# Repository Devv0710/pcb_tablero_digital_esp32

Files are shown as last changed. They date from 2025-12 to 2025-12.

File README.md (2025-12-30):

Este documento detalla las especificaciones técnicas y decisiones de diseño de hardware para la PCB de control de un tablero marcador digital. El sistema está basado en el microcontrolador **ESP8266 (Wemos D1 Mini)** y está diseñado para gestionar tiras LED direccionables de alta potencia y periféricos inductivos.

> **[IMAGEN 1: VISTA GENERAL DE LA PCB]**
>pcb

## 1. Arquitectura de Distribución de Potencia

El diseño gestiona dos rieles de alimentación independientes para evitar que el ruido de los actuadores y la carga de los LEDs interfieran con la estabilidad del microcontrolador.

> **[IMAGEN 2: DIAGRAMA DE BLOQUES DE POTENCIA U ORDENACIÓN FÍSICA]**
>
>

### Rail de Potencia Principal (5V)
* **Carga de LEDs:** El sistema controla 13 dígitos. El consumo máximo teórico es de **7.6A** (blanco al 100% de brillo), con un consumo típico de **400mA** por dígito en operación estándar.
* **Plano de Cobre:** Para soportar esta corriente sin caídas de tensión significativas (IR Drop), se utilizó un **plano de potencia de cobre** en la capa superior (Top Layer).
* **Protección:** Un fusible de acción rápida de **10A** (**F1**) protege la integridad de las pistas y componentes ante cortocircuitos en las tiras externas.

### Rail de Periféricos (12V)
* **Función:** Alimentación exclusiva para una bocina externa de alta potencia.
* **Consumo:** Optimizado para cargas menores a **1A**.
* **Control Electrónico:** Implementado mediante un MOSFET N-Channel **AO3400A**. 
* **Protección Inductiva:** Se incluyó un diodo de libre circulación (**1N4007**) en paralelo con la carga para suprimir los picos de fuerza contraelectromotriz al conmutar la bocina.  

## 2. Diseño de la PCB y Stackup

La placa se diseñó en **2 capas** con una estrategia de baja impedancia para manejar las altas corrientes involucradas.

### Capas y Planos (Copper Pours)

* **Capa Inferior (Bottom Layer - GND):** Utilizada íntegramente como un plano de masa continuo.
* **Capa Superior (Top Layer - 5V):** Aloja las señales y un plano de alimentación robusto para los 5V.
  
> **[IMAGEN 3: VISUALIZACIÓN DE LOS PLANOS DE COBRE EN KICAD]**
>
>

### Filtrado de Transitorios
Se implementó una red de desacoplo masiva con una capacitancia total cercana a los **10,000 uF** (incluyendo capacitores electrolíticos de **2200uF** y **1000uF**) para estabilizar el riel de 5V ante los cambios rápidos de estado de los LEDs.
## 3. Integridad de Señal y Lógica de Control

Para asegurar la comunicación fiable con los 13 dígitos de LEDs **WS2813**, se implementaron las siguientes etapas:

### Conversión de Niveles Lógicos (Level Shifting)
Dado que el ESP8266 opera a 3.3V y los LEDs requieren un umbral lógico cercano a 5V para evitar errores de datos, se incorporó un buffer de alta velocidad **74AHCT244**. Este componente asegura que los pulsos de datos tengan flancos de subida y bajada limpios y con la amplitud necesaria (5V).

### Terminación de Línea
Cada salida de datos hacia los dígitos incluye una resistencia serie de **330 Ohm**. Esto ayuda a:
* Reducir el *ringing* y las reflexiones en los cables de conexión.
* Proteger los pines de salida del buffer ante transitorios.

## 4. Selección de Componentes y Justificación

| Componente | Función | Justificación Técnica |
| :--- | :--- | :--- |
| **WS2813** | LEDs RGB | Posee un pin de **Backup Data**. Si un LED falla, la señal no se interrumpe. |
| **AO3400A** | MOSFET de Control | Baja resistencia $R_{DS(on)}$ para minimizar pérdidas térmicas en el control de la bocina (Carga < 1A). |
| **74AHCT244** | Level Shifter | Buffer de grado industrial para compatibilidad entre lógica CMOS de 3.3V y TTL de 5V. |

### Especificaciones de los LEDs (según Datasheet)
* **Corriente Quiescente:** < 0.6mA.
* **Intensidad Lumínica:** Rojo (380-600 mcd), Verde (1050-1500 mcd), Azul (270-400 mcd) a 16mA.
* **Longitud de onda:** Rojo (623nm), Verde (520nm), Azul (471nm).

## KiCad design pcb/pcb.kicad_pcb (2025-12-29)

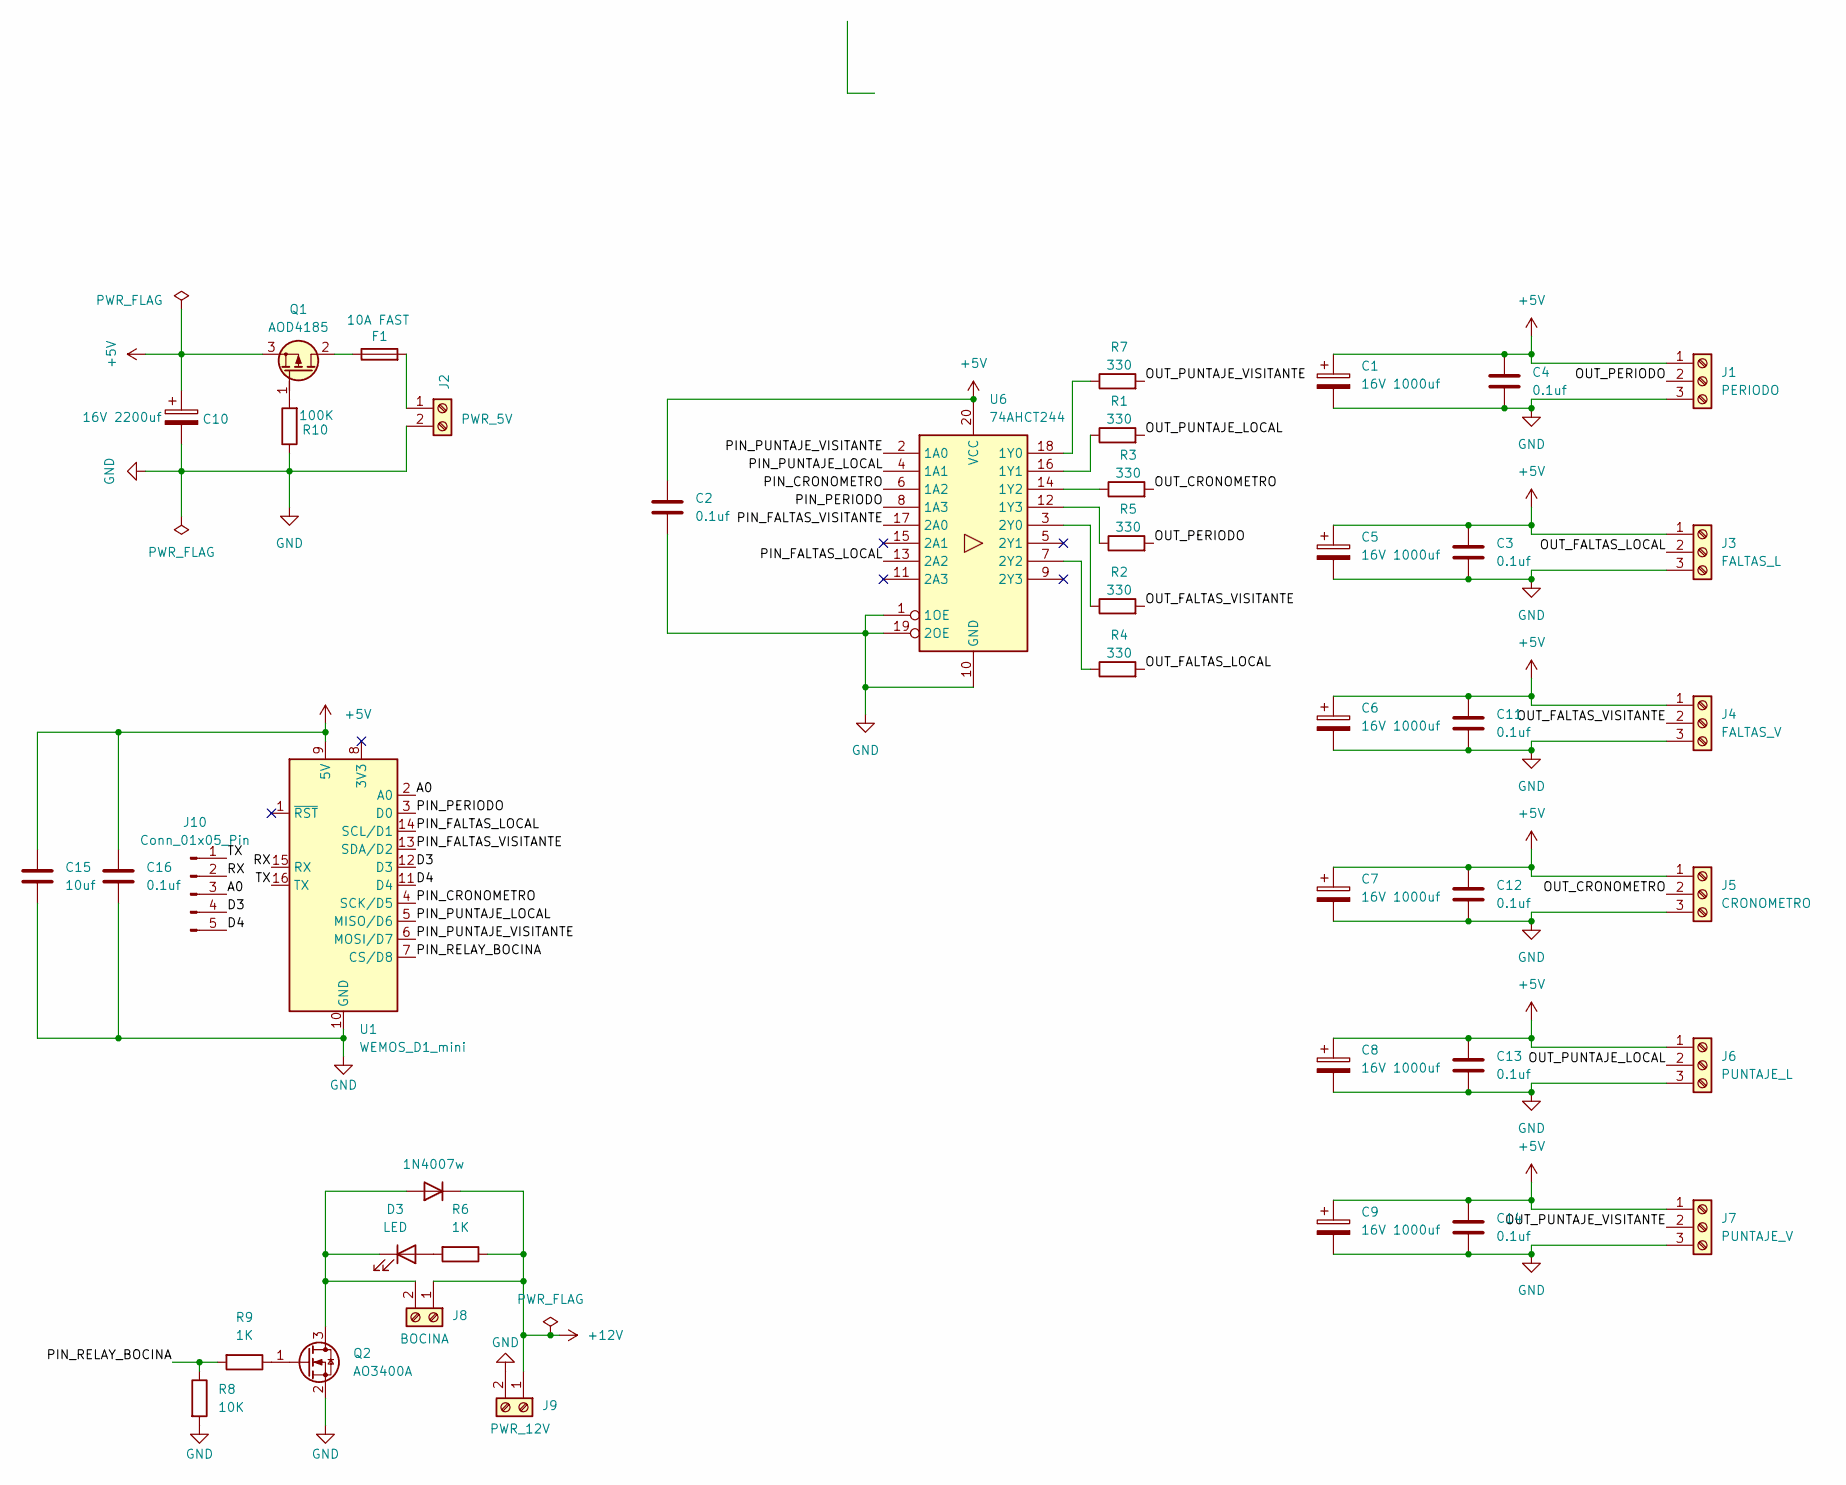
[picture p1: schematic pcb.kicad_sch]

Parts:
C1, C5, C6, C7, C8, C9: 16V 1000uf; CP_Radial_D10.0mm_P5.00mm
C2, C3, C4, C11, C12, C13, C14, C16: 0.1uf; C_0805_2012Metric
C10: 16V 2200uf; CP_Radial_D10.0mm_P5.00mm
C15: 10uf; C_0805_2012Metric
D2: 1N4007w; D_SOD-123
D3: LED; LED_0805_2012Metric_Pad1.15x1.40mm_HandSolder
F1: 10A FAST; Fuse_0603_1608Metric_Pad1.05x0.95mm_HandSolder
J1: PERIODO; TerminalBlock_Altech_AK300-3_P5.00mm
J2: PWR_5V; TerminalBlock_Altech_AK300-2_P5.00mm
J3: FALTAS_L; TerminalBlock_Altech_AK300-3_P5.00mm
J4: FALTAS_V; TerminalBlock_Altech_AK300-3_P5.00mm
J5: CRONOMETRO; TerminalBlock_Altech_AK300-3_P5.00mm
J6: PUNTAJE_L; TerminalBlock_Altech_AK300-3_P5.00mm
J7: PUNTAJE_V; TerminalBlock_Altech_AK300-3_P5.00mm
J8: BOCINA; TerminalBlock_Altech_AK300-2_P5.00mm
J9: PWR_12V; TerminalBlock_Altech_AK300-2_P5.00mm
J10: Conn_01x05_Pin; PinHeader_1x05_P2.54mm_Vertical
Q1: AOD4185; TO-252-2
Q2: AO3400A; SOT-23
R1, R2, R3, R4, R5, R7: 330; R_1206_3216Metric_Pad1.30x1.75mm_HandSolder
R6, R9: 1K; R_1206_3216Metric_Pad1.30x1.75mm_HandSolder
R8: 10K; R_1206_3216Metric_Pad1.30x1.75mm_HandSolder
R10: 100K; R_1206_3216Metric_Pad1.30x1.75mm_HandSolder
U1: WEMOS_D1_mini; WEMOS_D1_mini_light
U6: 74AHCT244; SO-20_12.8x7.5mm_P1.27mm

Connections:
+5V: C1.1, C2.1, C3.1, C4.1, C5.1, C6.1, C7.1, C8.1, C9.1, C10.1, C11.1, C12.1, C13.1, C14.1, C15.1, C16.1, J1.1, J3.1, J4.1, J5.1, J6.1, J7.1, Q1.3 (S), U1.9 (5V), U6.20 (VCC)
+12V: D2.1 (K), J8.1, J9.1, R6.1
/A0: J10.3, U1.2 (A0)
/D3: J10.4, U1.12 (D3)
/D4: J10.5, U1.11 (D4)
/OUT_CRONOMETRO: J5.2, R3.2
/OUT_FALTAS_LOCAL: J3.2, R4.2
/OUT_FALTAS_VISITANTE: J4.2, R2.2
/OUT_PERIODO: J1.2, R5.2
/OUT_PUNTAJE_LOCAL: J6.2, R1.2
/OUT_PUNTAJE_VISITANTE: J7.2, R7.2
/PIN_CRONOMETRO: U1.4 (SCK/D5), U6.6 (1A2)
/PIN_FALTAS_LOCAL: U1.14 (SCL/D1), U6.13 (2A2)
/PIN_FALTAS_VISITANTE: U1.13 (SDA/D2), U6.17 (2A0)
/PIN_PERIODO: U1.3 (D0), U6.8 (1A3)
/PIN_PUNTAJE_LOCAL: U1.5 (MISO/D6), U6.4 (1A1)
/PIN_PUNTAJE_VISITANTE: U1.6 (MOSI/D7), U6.2 (1A0)
/PIN_RELAY_BOCINA: R8.1, R9.2, U1.7 (CS/D8)
/RX: J10.2, U1.15 (RX)
/TX: J10.1, U1.16 (TX)
GND: C1.2, C2.2, C3.2, C4.2, C5.2, C6.2, C7.2, C8.2, C9.2, C10.2, C11.2, C12.2, C13.2, C14.2, C15.2, C16.2, J1.3, J2.2, J3.3, J4.3, J5.3, J6.3, J7.3, J9.2, Q2.2 (S), R8.2, R10.1, U1.10 (GND), U6.1 (1OE), U6.10 (GND), U6.19 (2OE)
unnamed: D2.2 (A), D3.1 (K), J8.2, Q2.3 (D)
unnamed: D3.2 (A), R6.2
unnamed: F1.2, J2.1
unnamed: F1.1, Q1.2 (D)
unnamed: Q1.1 (G), R10.2
unnamed: Q2.1 (G), R9.1
unnamed: R7.1, U6.18 (1Y0)
unnamed: R1.1, U6.16 (1Y1)
unnamed: R3.1, U6.14 (1Y2)
unnamed: R5.1, U6.12 (1Y3)
unnamed: R2.1, U6.3 (2Y0)
unnamed: R4.1, U6.7 (2Y2)

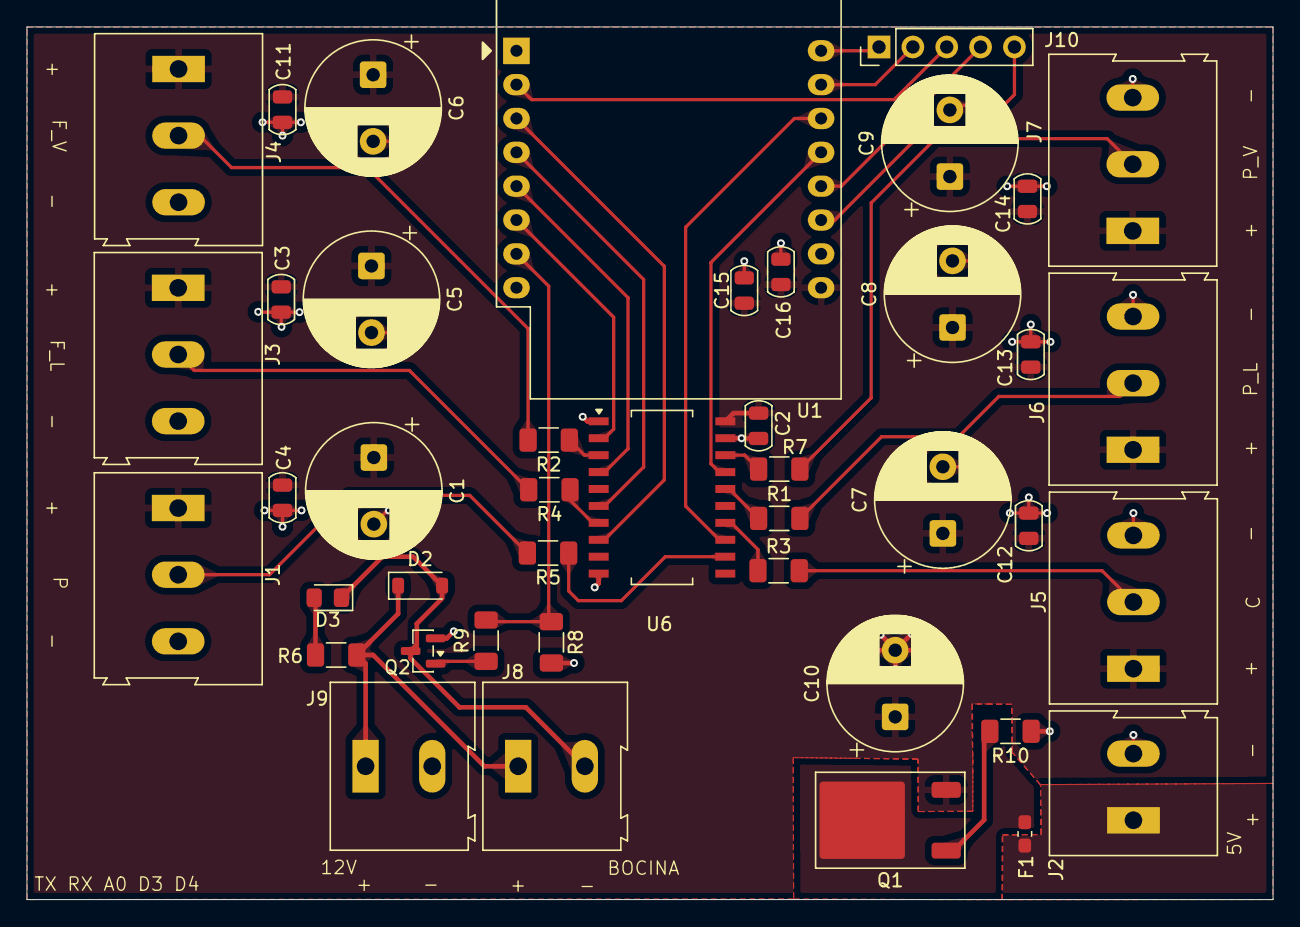
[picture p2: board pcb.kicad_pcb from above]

Board: 2 copper layers, 93.5 x 65.5 mm, 43 parts (0 on the bottom side), 33 nets.

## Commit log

2025-11-14 v1, con relay integrado, proteciones para polaridad inversa y fusible.
    [pcb.kicad_pcb, pcb.kicad_sch]
2025-12-22 refactor: optimize power efficiency and reduce PCB footprint
    Replace series protection diode with P-Channel MOSFET (AOD4185) to minimize voltage drop.
    Migrate from ESP32-DevKitC to Wemos D1 Mini (ESP8266) for cost and size reduction.
    Replace mechanical relay with N-Channel MOSFET for silent and efficient buzzer control.
    Update schematics and PCB layout accordingly.
    [pcb.kicad_pcb, pcb.kicad_sch, untitled.kicad_sch]
2025-12-29 feat(pcb): Actualizar diseño y eliminar esquemático obsoleto
    - Reemplaza conector de 6 por 5 pines en el esquemático.
    - Regenera el layout del PCB y actualiza el ruteado.
    - Añade nuevo ancho de pista de 0.35mm en la configuración.
    - Elimina el archivo de esquemático no utilizado 'untitled.kicad_sch'.
    [pcb.kicad_pcb, pcb.kicad_sch, untitled.kicad_sch]
2025-12-30 Agregar especificaciones técnicas de la PCB
    Este documento detalla las especificaciones técnicas y decisiones de diseño de hardware para la PCB de control de un tablero marcador digital basado en el microcontrolador ESP8266.
